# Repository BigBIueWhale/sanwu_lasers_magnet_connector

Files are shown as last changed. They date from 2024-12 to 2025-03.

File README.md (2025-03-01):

# Problem Statement

**Disclaimer:** This project is not affiliated with SanwuLasers™️ company.

SanwuLasers™️ Lasers such as Striker, Challenger II, "Laser Rangers" all have option for high powered blue diode (~7 watts).

SanwuLasers™️ offers flashlight adapters that [can be screwed onto the laser head](./docs/laser_and_flashlight_adapter.jpg). It's generic, the flashlight adapter fits all of the aforementioned host types.

Problem is: It takes way too long to physically unscrew the flashlight adapter, and it's way too annoying to screw it back on. It should be possible to just pull it off, and snap it right back into place 🧲.

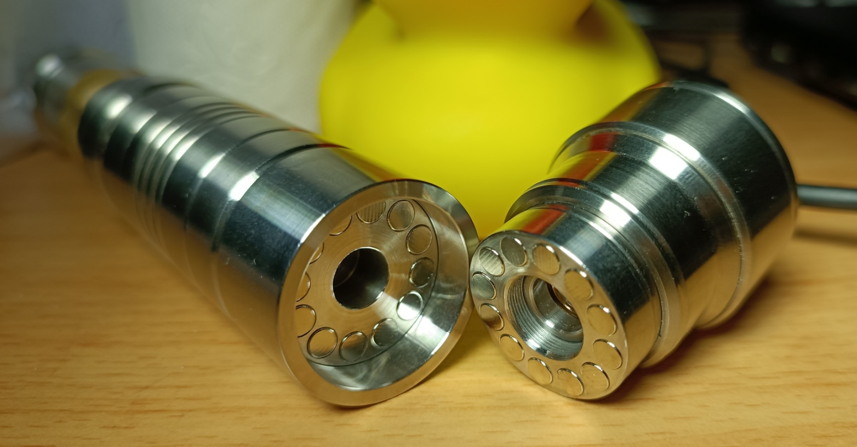
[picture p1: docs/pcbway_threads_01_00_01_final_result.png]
Fully assembled


# Solution

[Manufacture](#manufacture-with-pcbway-cnc) and [assemble](#assembly) a stainless steel adapter, converting the screw-on mechanism into  a robust magnetic mechanism.

## Manufacture with PCBWay CNC

### Compatibility

The current [rangers_guard_sleeve_01_00_01](#rangers_guard_sleeve_01_00_01) piece is only compatible with Sanwu **"Laser Rangers"** with [body models 1, 2, 4, 5, 7, 8](./docs/laser_rangers_body_models.png) due to [the 2-stair design](./docs/guard_sleeve_01_00_01_rangers_head.jpg).\
I recommend body model 7 or model 2, they have good grip ✊.

### Price
Price overview of [January 2025 order](./docs/pcbway_order_price_01_00_00.png) containing 3 items [male_thread_01_00_00](#male_thread_01_00_00) + [female_thread_01_00_00](#female_thread_01_00_00) + [rangers_guard_sleeve_01_00_01](#rangers_guard_sleeve_01_00_01):
1. **Items**: $113.73 USD (= ₪405.52 New Israeli Shekels)
2. **Shipping Fedex to Israel**: $40 USD (= ₪142.62 New Israeli Shekels)
3. **Israel customs import tax 🖕**: ₪235.46 New Israeli Shekels.\
Automatically charged by FEDEX CAYMAN ISLANDS same day as order arrival because I have a Fedex account.

**Total**: ~ ₪783.6 New Israeli Shekels when ordering to Israel.

### Order

PCBWay CNC service has shown ability to successfully manufacture [the threads](#threads) needed for the parts in this project (as of February 2025), but they don't guarantee successful manufacture of non-standard threads.

1. Sign-in to your PCBWay account, and upload each step file to [PCBWay CNC machining](./docs/pcbway_cnc_machining_upload.png). Start by uploading [male_thread.step](./male_thread_01_00_00/male_thread.step).

2. For all parts, choose material [stainless steel 303](./docs/pcbway_choose_stainless_steel_303.png).

3. For the `male_thread` and `female_thread` parts, click "Yes" on [Do your parts need to tap threads?](./docs/pcbway_click_yes_on_threads_and_tapped_holes.png)\
A [pop-up menu](./docs/pcbway_upload_technical_drawing.png) will appear- upload the relevant technical drawing for the current piece: [male_thread technical drawing](./male_thread_01_00_00/technical_drawing/technical_drawing.png) / [female_thread technical drawing](./female_thread_01_00_00/technical_drawing/technical_drawing.png).\
Leave `Inserts` marked "No" because our parts don't have any inserts.

4. For all parts, choose "Surface Finish" -> `Standard (As-Milled) (Ra 125μin)`.

5. For the `male_thread` and `female_thread` parts, choose "Surface Roughness" -> `125uin/3.2um Ra`.\
You can't change the default surface surface finish on `rangers_guard_sleeve` because we don't have a technical drawing for it.

6. For all parts, choose product description [robot components](./docs/pcbway_product_description_robot_parts.png) for import/customs purposes.\
Not sure if that's the best thing to report for Israeli customs but that's the option I've been choosing.

7. **Repeat steps 2 -> 6** for [female_thread.step](./female_thread_01_00_00/female_thread.step) and then again for [rangers_guard_sleeve.step](./rangers_guard_sleeve_01_00_01/rangers_guard_sleeve.step).\
Fill in the items for all 3 orders in the same window, and each time scroll down and [select additional files](./docs/pcbway_select_additional_step_files.png).

8. Click botton [submit request](./docs/pcbway_ready_to_submit_request.png).

9. After ~24 hours PCBWay will supply you with a price quote- hopefully no higher than initially estimated. Then you'll have the option to make the order (after a human has viewed your request).

10. Once you receive the parts, follow [Assembly](#assembly) steps.

# Development Process

Classical GUI-based CAD softwares are problematic for multiple reasons:

1. Sometimes requires user to draw shapes like an artist 🎨🧑‍🎨 instead of using precise definitions.

2. Write-only designs. A simple change in a basic parameter can require starting the design from scratch.

3. Cost money / require online connection- **FreeCAD 1.0.0** is no good yet. Wasn't able to find option to place multiple evenly-spaced holes around a radius.

4. Not text. Can you search "4.11" and change all occurences to a larger / smaller value? Can you ask ChatGPT for help with your design?

I decided it's more robust to define the 3d design with words and precise measurements than it is to use a GUI software.

Therefore I helped `ChatGPT o1` use Python library `import cadquery as cq` to create my 3d designs.

# Magnets

The custom machined male and female parts have 12 holes each, 3.30mm depth and 4.11mm diameter.

These sizes were fine tuned for a stack of two of the [neodymium disc magnets](./docs/neodymium_magnets_amazon_listing.png) I chose.

According to the listing these are **2mm in height** but notice that the [diameter is greater](./docs/amazon_magnet_diameter_not_as_advertized.jpg) and [height is much less](./docs/amazon_magnet_height_not_as_advertized.jpg) than advertized.

When stacking two magnets per hole, the magnets are **very** slightly extruding (0.15mm), for total of 0.3mm extra [gap created by the magnets](./docs/tight_fit_despite_magnets_slightly_extruding.jpg).

The small gap is also a feature- it causes the flashlight adapter to **not** be air-tight which makes it easier to change focus without causing a vacuum (which was always a feature that was bothering me in the default flashlight adapter behaviour).

I originally chose 4.04mm hole width but that was not enough, so then I changed the design to 4.16mm hole to make it easier to push-in the magnets. I then changed the design to 4.11mm diameter for a tight fit- so you now have to push-in each bottom magnet with a bench vice.

# Threads

Sanwu uses the following threading specs for the laser head and attachments:

- Male:
  ```txt
  CNC machined
  Metric right-handed male threaded rod
  11.45mm diameter teeth (crest-to-crest). 0.05mm smaller diameter than the female tap.
  0.5mm pitch
  3mm length out of which only the tip 2mm are threaded and the base 1mm runoff is shaved down and not threaded.
  That's total of 4 threads.
  ```
- Female (laser head):
  ```txt
  CNC machined
  Metric right-handed female
  m11.5x0.5 tap (11.5mm diameter, 0.5mm pitch)
  6mm depth- total of 12 threads
  ```

This adheres to standard: https://www.gewinde-normen.de/en/iso-fine-thread-2.html
```txt
ISO Metric Fine Thread DIN 13-3
Pitch mm: 0.5
Nominal (major) Diameter mm: M 11.5
```
Issue is that the aforementioned size is not a standard combination of **major diameter** + **pitch**.\
PCBWay CNC was able to machine it- because supposedly it's a standard size in China.

# Recreate 3d model from code

You can decide to change parameters in any of [male_thread.py](./male_thread_01_00_00/male_thread.py), [female_thread.py](./female_thread_01_00_00/female_thread.py), [rangers_guard_sleeve.py](./rangers_guard_sleeve_01_00_01/rangers_guard_sleeve.py) then re-run the script to update the design files.

Always update [male_thread_visual.py](./male_thread_01_00_00/male_thread_visual.py) in the same way you updated [male_thread.py](./male_thread_01_00_00/male_thread.py).\
Always update [female_thread_visual.py](./female_thread_01_00_00/female_thread_visual.py) in the same way you updated [female_thread.py](./female_thread_01_00_00/female_thread.py).

If you made a visual change to [male_thread.py](./male_thread_01_00_00/male_thread.py) or [female_thread.py](./female_thread_01_00_00/female_thread.py) then you should update [technical_drawing.png](./male_thread_01_00_00/technical_drawing/technical_drawing.png) / [technical_drawing.png](./female_thread_01_00_00/technical_drawing/technical_drawing.png) in **Microsoft Paint**.

The `XX_visual.py` files exist solely for technical drawing purposes- and each generates a `XX_visual.stl` file.\
Feel free to use [create_images.py](./male_thread_01_00_00/technical_drawing/create_images.py) / [create_images.py](./female_thread_01_00_00/technical_drawing/create_images.py) to generate updated images for use in the the technical drawing you're updating.

## Software Requirements
- Tested on Windows 11 Pro 23H2
- Ran with Python 3.10.6
- Specific versions chose: `pip install cadquery==2.4.0 numpy==1.23.5`

## Assembly

1. Prepare [the male & female pieces](./docs/pcbway_male_female_threads_01_00_00_raw.jpg), [the magnets](./docs/magnets_box_findmag.jpg), and a bench vice.

2. Insert a stack of 2 magnets with your hands into one of the holes- it won't push-in all the way and the top magnet will stick ~1mm out of the hole (as opposed to ~0.15mm when pushed in all the way).

3. Use a bench vice to push the stack all the way down- the bottom magnet is now stuck down there and will never come out, no glue needed.\
The top magnet is slightly sticking out (only ~0.15mm) and in practice is loose.

4. Use a stack of magnets to pull out the top magnet. If it comes out- good!\
If the top magnet doesn't come out by using attraction (due to machining tolerances) even when the entire piece is heated to 50° celsius (expanding the steel), that means we don't have to use glue for that hole.

5. Repeat steps 2 -> 4 for every hole in both pieces male and female. Insert the magnets into the holes in either clockwise or counter clockwise order, placing in the magnets in **alternating polarities**- positive hole, negative hole, positive hole, negative hole. This is so the magnetic power doesn't accumulate. Essentially, so the entire piece as a whole doesn't become significantly magnetic. Also, this make every adjacent pair of magnets attracted to each other so they're "happy to be there".\
We have now finished pushing-in a total of 24 magnets to the bottom of the 24 holes- and they're mechanically held in place quite tightly- and in the correct polarities.

6. Wear black nitrile gloves and protective goggles (laser safety goggles work)- and prepare the [super glue](./docs/good_super_glue_brand.jpg).\
Prepare paper towel as well to wipe off excess super glue. Move entire work area to baking paper surface to avoid sticking.\
Keep a bench vice nearby just in case.

7. **Note:** If a bottom magnet is loose in its hole (due to machining mishaps)- then you can use super glue on the entire stack of 2 magnets in one push. **Never use super glue more than once per hole** because that would cause an unreparable gap between the bottom magnet and the top magnet (due to the dried super glue) then you'll have to throw away the entire piece (I say this from experience). 

8. Apply 1 drop of super glue into one of the holes by tapping the bottom magnet of the hole with the head of the nozzle.

9. Hold the stack of magnets in the correct polarity for the hole, and quickly insert the top magnet and slide off the rest of the stack of magnets (such that now a stack of 2 magnets is in the hole). Quickly wipe the bottom of the magnet stack on paper towel to avoid the negative effect of excess super glue contaminating the magnet stack.\
Immediately push down hard on the just-inserted magnet with the same paper towel while rubbing away excess super glue.\
If even when pushing down with paper towel you see that the magnet isn't pushed-in all the way: use a bench vice ASAP. If only a minute has passed you might still have a chance to push the top magnet down to stop it from permanently sticking out.

10. Don't worry, you can reuse the paper towel because super glue immediately dries when exposed to paper towel. However- after each magnet insertion make sure to wipe off any drips of liquid super glue that may have fallen onto the baking paper's surface.

11. Repeat steps 7 -> 10 for each of the 24 holes.

12. Take a [rangers_guard_sleeve](#rangers_guard_sleeve_01_00_00) and the [male_thread](#male_thread_01_00_00) piece you just inserted 12 pairs of magnets into. Practice sliding the [male_thread](#male_thread_01_00_00) piece [screw side down](./docs/guard_sleeve_01_00_01_rangers_head.jpg) into the top of the [rangers_guard_sleeve](#rangers_guard_sleeve_01_00_00) piece.\
It's actually not that easy to push the piece [all the way down](./docs/guard_sleeve_01_00_01_assembled_bottom_view.jpg) because of the tight tolerance.\
Prepare Q-Tips and paper towel.

13. Precisely apply a small amount of super glue to [the inside of the bottom ring](./docs/guard_sleeve_01_00_01_inside_of_bottom_ring.jpg) then quickly slide-in the [male_thread](#male_thread_01_00_00) all the way down.

14. Very quickly start wiping the [top ring](./docs/guard_sleeve_01_00_01_top_ring.jpg) with paper towel. Just as quickly [wipe the bottom](./docs/guard_sleeve_01_00_01_area_to_wipe.jpg) with Q-tips to avoid any significant width of excess super glue from hardening.

15. If you failed to push all the way down (and the super glue hardened), push the [male_thread](#male_thread_01_00_00) out of the [rangers_guard_sleeve](#rangers_guard_sleeve_01_00_00) using a bench vice. Optionally, take [the female side](./docs/sanwu_striker_adapter_female_view.jpg) of a [Sanwu adapter for striker](./docs/sanwu_adapter_order_separately.png) to [gain leverage](./docs/gain_leverage.jpg) with the bench vice (without damaging our machined part).\
Finally scrape off the previously-applied super glue using a needle or other sharp metal rod, or by pushing in-and-out the [male_thread](#male_thread_01_00_00). Then try again to repeat steps 13 -> 14.

# Release Notes

## female_thread_01_00_00
[female_thread.py](./female_thread_01_00_00/female_thread.py)\
[PCBWay raw result](./docs/pcbway_female_thread_01_00_00_raw.jpg)\
Based on [magnet_holes_01_00_01](#magnet_holes_01_00_01)\
[Final result](./docs/pcbway_threads_01_00_01_final_result.png)

- Only female, not generic. With builtin female threading (screw hole) instead of relying on [purchasing adapter from Sanwu](#threads) and using angle grinder.

- Smaller cylinder diameter- 24mm instead of 28mm. This is possible because that pesky Sanwu adapter used to take up 17.6mm in diameter where we couldn't place any magnets.

- Height- 6mm instead of 8.3mm. Small improvement to bulkiness in addition to the smaller male piece.

- To be utilized with [rangers_guard_sleeve_01_00_00](#rangers_guard_sleeve_01_00_00) instead of [rangers_guard_sleeve_01_00_01](#rangers_guard_sleeve_01_00_01).

- [Technical drawing](./female_thread_01_00_00/technical_drawing/technical_drawing.png) so that PCBWay can correctly manufacture the threads.

- 12 magnet holes instead of 16 (because we're now smaller). Should still be strong enough.

- 4.16mm magnet holes diameter was too big so I changed the design to 4.11mm diameter for a perfect fit.

- 1 unit ordered [via PCBWay](./docs/pcbway_order_price_01_00_00.png)

## male_thread_01_00_00
[male_thread.py](./male_thread_01_00_00/male_thread.py)\
[PCBWay raw result top](./docs/pcbway_male_thread_01_00_00_raw.jpg)\
[PCBWay raw result bottom](./docs/pcbway_male_female_threads_01_00_00_raw.jpg)\
Based on [magnet_holes_01_00_01](#magnet_holes_01_00_01)\
[Final result](./docs/pcbway_threads_01_00_01_final_result.png)

- Only male, not generic. With builtin male threading (screw) instead of relying on [purchasing adapter from Sanwu](#threads) and using angle grinder.

- Smaller cylinder diameter- 24mm instead of 28mm. This is possible because that pesky Sanwu adapter used to take up 17.6mm in diameter where we couldn't place any magnets.

- Height- 4.3mm (not including male thread rod) instead of 8.3mm. This makes the entire assembled system less bulky.

- To be utilized with [rangers_guard_sleeve_01_00_00](#rangers_guard_sleeve_01_00_00) instead of [rangers_guard_sleeve_01_00_01](#rangers_guard_sleeve_01_00_01).

- [Technical drawing](./male_thread_01_00_00/technical_drawing/technical_drawing.png) so that PCBWay can correctly manufacture the threads.

- 12 magnet holes instead of 16 (because we're now smaller). Should still be strong enough.

- 4.16mm magnet holes diameter was too big so I changed the design to 4.11mm diameter for a perfect fit.

- 1 unit ordered [via PCBWay](./docs/pcbway_order_price_01_00_00.png)

## rangers_guard_sleeve_01_00_01
[rangers_guard_sleeve_01_00_00.py](./rangers_guard_sleeve_01_00_01/rangers_guard_sleeve.py)\
[PCBWay raw result](./docs/pcbway_guard_sleeve_01_00_01_raw.jpg)\
[Final result](./docs/pcbway_threads_01_00_01_final_result.png)

- Slightly narrower steps- so the fit onto the Laser Rangers head is more snug and secure (less dependent on screw mechanism)

- Different length and internal and external diameters to fit the now smaller and thinner [male_thread](./male_thread_01_00_00/) and [female_thread](./female_thread_01_00_00/)

- Compatible with [male_thread_01_00_00](#male_thread_01_00_00) & [female_thread_01_00_00](#female_thread_01_00_00).

- 1 unit ordered [via PCBWay](./docs/pcbway_order_price_01_00_00.png)

## rangers_guard_sleeve_01_00_00
[rangers_guard_sleeve_01_00_00.py](./old/rangers_guard_sleeve_01_00_00.py)\
[PCBWay raw result](./docs/pcbway_guard_sleeve_01_00_01_raw.jpg)

- Designed to be attached on with [super glue](./docs/bad_super_glue_brand.jpg) to a `magnet_holes` piece (to the male side that's screwed onto the laser head).

- Keeps flashlight head secure on Laser Rangers model so it can only be pulled off straight-up which is the direction the magnets are strongest in.

- Fills-in ugly gap at the stairs of the **Laser Rangers** laser head- only compatible with [models 1, 2, 4, 5, 7, 8](./docs/laser_rangers_body_models.png). I recommend model 7 or model 2.

- Compatible with [magnet_holes_01_00_00](#magnet_holes_01_00_00) and with [magnet_holes_01_00_01](#magnet_holes_01_00_01)

- 2 units ordered [via PCBWay](./docs/pcbway_order_01.png)

## magnet_holes_01_00_01
[magnet_holes_01_00_01.py](./old/magnet_holes_01_00_01.py)\
[PCBWay raw result](./docs/pcbway_magnet_holes_and_guard_sleeve.jpg)

- 4.16mm diameter magnet holes for better fitting, instead of 4.04mm

- 2 units ordered [via PCBWay](./docs/pcbway_order_01.png)

## magnet_holes_01_00_00
[magnet_holes_01_00_00.py](./old/magnet_holes_01_00_00.py)\
[Xometry raw result](./docs/xometry_raw_result.jpg)\
[Final result](./docs/xometry_final_result.jpg)

- 4.04mm diameter magnet holes

- Generic- can be used with `rangers_guard_sleeve_01_00_00`.

- Generic- each piece can be used with [Sanwu Adapter](#threads) male or female.

- Generic- since the magnets [perfectly fit](./docs/tight_fit_despite_magnets_slightly_extruding.jpg), the male and female sides are interchangeable.

- 5 units ordered with https://get.xometry.eu/payments/ec0325ff-71c7-4672-9496-26f8077902b1

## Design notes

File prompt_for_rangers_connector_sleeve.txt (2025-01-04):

I had this CNC machined in stainless steel 303. Specifically I had two of these manufactured to be used one on top of the other (face to face, magnets attaching to each other).

Now I need you to create an entirely new Python file that produces for me: `rangers_guard_sleeve_01_00_00.py`.

I will provide the entire readme of my full project for you to glance at to give you further context, **then** I will explain the requirements for the `rangers_guard_sleeve` after you read the readme, and see the provided example code.

magnet_holes_01_00_01.py
```py
"""
Creates a 'toilet paper roll' shaped cylinder with:
  - Outer diameter: 28.0 mm
  - Inner hole diameter: 17.6 mm (fully through)
  - Height: 8.3 mm
Then adds 16 equally spaced magnet holes at the top:
  - Diameter: 4.10 mm
  - Depth: 3.3 mm
  - Circle radius for hole centers: 11.4 mm
Exports the model to both STL and STEP formats.
"""

import cadquery as cq

# === 1. Create main cylinder ===
#   - Outer diameter: 28 mm → radius = 14 mm
#   - Height: 8.3 mm
model = (
    cq.Workplane("XY")
    .circle(14)        # radius for 28 mm diameter
    .extrude(8.3)      # height
)

# === 2. Hollow out the center (like a toilet paper roll) ===
#   - Through-hole with diameter: 17.6 mm → radius = 8.8 mm
model = (
    model
    .faces(">Z")               # pick the top face
    .workplane()               # create a new workplane on that face
    .hole(17.6)                # cut a 17.6 mm diameter hole all the way through
)

# === 3. Drill the magnet holes around the top face ===
#   - 16 holes
#   - Each hole diameter: 4.10 mm
#   - Hole depth: 3.3 mm
#   - Hole centers on a circle of radius: 11.4 mm
#     so they are equally spaced 360/16=22.5 degrees apart
model = (
    model
    .faces(">Z")               # pick the top face again
    .workplane()               # new workplane for drilling
    .polarArray(radius=11.4, startAngle=0, angle=360, count=16, fill=True)  # 16 holes in a full circle
    .hole(diameter=4.10, depth=3.3)  # create the holes as pockets in the top
)

# === 4. Export the final model to both STL and STEP files ===
output_file_step = "magnet_holes.step"
output_file_stl = "magnet_holes.stl"

# Export to STEP format
cq.exporters.export(model, output_file_step)

# Export to STL format
cq.exporters.export(model, output_file_stl)

# Print file names for confirmation
print(f"Model exported to: {output_file_step}")
print(f"Model exported to: {output_file_stl}")
```

```md
# Problem Statement

SanwuLasers™️ Lasers such as Striker, Challenger II, Laser Rangers all have option for high powered blue diode (~7 watts).

SanwuLasers™️ offers flashlight adapters that [can be screwed onto the top](./docs/laser_and_flashlight_adapter.jpg). It's generic, the flashlight adapter fits all of the aforementioned host types.

Problem is: It takes way too long to physically unscrew the flashlight adapter, and it's way too annoying to screw it back on. It should be possible to just pull it off, and snap it right back in place 🧲.

[magnet holes standard triangle language](./magnet_holes.stl)

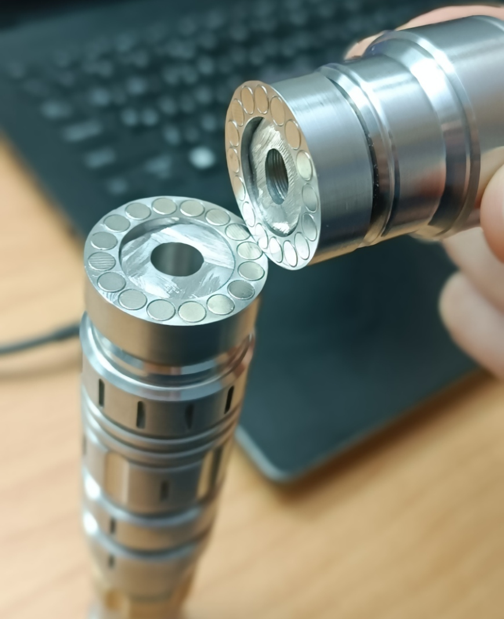
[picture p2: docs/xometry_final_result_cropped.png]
Fully assembled


# Solution

Custom order for CNC machined stainless steel part that converts the screw-on mechanism into a magnetic mechanism!

The flashlight adapter can be ordered with an [Adapter for striker](#threads). This adapter is super useful because it's already threaded with male and female sides.

The generic custom machined part has 16 small holes, each 4.10mm in diameter and 3.30mm depth.

It just so happens that in practice, my choice of 3.30mm depth works with the [neodymium disc magnets](./docs/neodymium_magnets_amazon_listing.png) I chose, which according to the listing are **2mm in height** (apparently they're less). 

It just so happens that the specific magnets I bought, somehow [fit perfectly](./docs/two_stacked_magnets_fit_in_3.3mm_hole_perfectly.jpg) into the 3.3mm hole when two are stacked on each other in each hole and with super glue prepared at the bottom (no super glue between the two magnets).

The magnets are **very** slightly extruding which does cause purple light to be slightly visible when flashlight mode is on, but it's still a [tight fit](./docs/tight_fit_despite_magnets_slightly_extruding.jpg).

The small gap is also a feature- it causes the flashlight adapter to **not** be air-tight which makes it easier to change focus without causing a vacuum (which was a feature that was bothering me in the default flashlight adapter behaviour).

I originally chose 4.04mm hole width but that was not enough to leave room for machine tolerance and temperature changes, so then I changed the design to 4.10mm hole to make it easier to push-in the magnets.

# Process

I learned the recently released `FreeCAD 1.0.0`, but I gave up on the design once I understood that the software requires the user to draw shapes with my laptop's touchpad. I'm not an artist 🎨🧑‍🎨.

I decided it's much more robust to define the 3d design with words and precise measurements than it is to start drawing like a preschool child.

Therefore **for the initial version** I had `ChatGPT o1` write Python code to generate both a `.step` file and an `.stl` file, using [this prompt](./prompt.txt).

I use the `.stl` file to view the design in `Microsoft Paint 3d`, I then uploaded the `.step` file as-is to `Xometry` website.

I chose standard stainless steel [settings in the website](./docs/xometry_order_settings.png) with the lowest tolerance quality.

The reason I chose such a low tolerance quality is that I'm using super glue and I made the holes slightly bigger than they need to be, so it's fine. Also, I want the CNC machine to just do everything automatically to avoice human error.

# Threads

This adapter from SanwuLasers™️ is the base of my design.\
It already comes with [male threads](./docs/sanwu_striker_adapter_male_view.jpg) and [female threads](./docs/sanwu_striker_adapter_female_view.jpg).

The part can be ordered via its [dedicated listing](./docs/sanwu_adapter_order_separately.png) on the website, or as part of the [flashlight converter listing](./docs/sanwu_adapter_in_flashlight_converter_listing.png).

The adapter is 17.55 mm in diameter, so I cut a 17.60mm hole in the cylinder of my custom design.

I [cut the adapter in half](./docs/sanwu_adapter_cut_in_half.jpg) using a [diamond blade circular saw](./docs/angle_grinder/angle_grinder_readme.pdf), sand it down, and super glue the male part into the large hole in one of my generic custom machined parts, and the female part of the adapter from Sanwu into another unit of my generic custom machined part.

This is my alternative to reverse-engineering the threads that Sanwu uses.

Just for general knowledge, Sanwu uses the following threading specs:

- Male:
  ```txt
  CNC machined
  Metric right-handed male threaded rod
  11.45mm diameter teeth (crest-to-crest). 0.05mm smaller diameter than the female tap.
  0.5mm pitch
  3mm length out of which only the tip 2mm are threaded and the base 1mm runoff is shaved down and not threaded.
  That's total of 4 threads.
  ```
- Female (laser head):
  ```txt
  CNC machined
  Metric right-handed female
  m11.5x0.5 tap (11.5mm diameter, 0.5mm pitch)
  6mm depth- total of 12 threads
  ```

I chose to use threads from an existing SanwuLasers™️ adapter instead of printing my custom part [with designed threads](./docs/attempt_design_screw.png) for multiple reasons:
1. 11.5mm diameter is not standard.
2. Thread specification required English language specification, and can only exist in a step file for show (being pretty). This makes the whole process more expensive, and less automatic- it might make it hard for the CNC machine to know what to do!
3. I can always later design another custom stainless steel piece to fit into the generic 17.60mm hole with super glue, and I can decide to make it have threads! This incurs less risk by making the components modular.
4. Generic- single design works as either male or female screw side. Only having to print one step file multiple times is significantly cheaper because it only requires one preparation stage for Xometry.

# Recreate 3d model from code

You can decide to change parameters in [main.py](./main.py) then re-run the script to update the design files.

## Requirements
- Tested on Windows 11 Pro 23H2
- Ran with Python 3.10.6
- Specific versions chose: `pip install cadquery==2.4.0 numpy==1.23.5`

## Run
1. Delete the existing `.step` file and `.stl` file.
2. Run command `python magnet_holes_01_00_01.py` in a cmd Window in the same directory as the project folder.
3. Use the newly created `magnet_holes.stl` and `magnet_holes.step` for the male and female sides (upload to PCBWay CNC machining, or to Xometry).

# Release Notes

## magnet_holes_01_00_01
- 4.10mm diameter magnet holes for better fitting

## magnet_holes_01_00_00
[magnet_holes_01_00_00.py](./magnet_holes_01_00_00.py)\
[Final result](./docs/xometry_final_result.jpg)

- 4.04mm diameter magnet holes
- 5 units ordered with https://get.xometry.eu/payments/ec0325ff-71c7-4672-9496-26f8077902b1
```

# Instructions

Well, you saw what ChatGPT already managed to do, so I already have my hopes up for you to deliver and idiomatic and correct design!

Now let's get back to `rangers_guard_sleeve`.

The goal is to make it so the only way to pull off the flashlight head is directly up, so it cannot possibly accidentally fall off.

The Sanwu Striker has a build that is already sunk in, and that works great in stopping the flashlight adapter from accidentally breaking off / sliding off, so this design is specifically for the Sanwu Laser Rangers model which doesn't have that builtin fortunate compatibility.

Since we're designing the sleeve specifically for the `Rangers` we'll also make some cuts for the "stairs" that are manufactured into the head of most Laser Rangers models from Sanwu Lasers™️. These cuts won't be compatible with body types 3, 6, 9 (as seen in the listing at https://www.sanwulasers.com/product/laserrangers) which only have one stair on the head.

1. Start with a 30.20mm diameter, 23.2mm height cylinder as the base shape.

This is purposefully ~2mm wider than the 28mm diameter `magnet_holes`, to give us a 1mm wall thickness after some pockets, at the thinnest part of the design (which is the minimum for stainless steel).

2. Cut out a circular pocket 21.10mm in diameter from the center of the bottom of the base cylinder all the way to the top.

This is to fit the thinnest shape in this design- the top stair that is 21.00mm in diameter

3. Cut out a centered circular pocket at the top of the base cylinder, should be 28.10mm diameter pocket that has a 16.90mm depth.

Purpose: to tightly fit the bottom `magnet_holes` (male) piece as a structural hold to this entire design, with superglew to the base male piece that is screwed on to the laser head.\
16.9mm is the height of 2 `magnet_holes` + the gap between them.\
28.20mm is slightly wider than the 28mm wide `magnet_holes` cylinder diameter.

4. Cut out a slightly wider centered circular pocket at the top of the base cylinder (in addition to the one we already drilled out at the top), should be 28.20mm diameter pocket and 8.40mm depth.

Purpose: loosely fit the top `magnet_holes` (female) piece and stop it from accidentally disattaching while not blocking a user from yanking it upwards.\
8.40mm is slightly taller than 8.30mm which is the height of a single `magnet_holes` piece.\
28.20mm is purposefully wider than the 28mm wide `magnet_holes` cylinder diameter, and leaves walls that are exactly 1mm thick.

4. Cut out a wider centered circular pocket at the bottom of the base cylinder (in addition to the one we already drilled out at the bottom). It should be 25.10mm in diameter and 4.00mm in depth.

This is for the bottom stair which is 25.00mm in diameter.\
The total hight of the area of the stairs we want to encompass is 6.30mm in height, and I measured that for at least 2.30mm out of that total stair height the **small** stair is no more than 21.10mm. The pocket for the small stair was already dug out in an earlier step, therefore in this step we only dig in 6.30mm - 2.30mm == 4.00mm from the bottom.

Get to work!

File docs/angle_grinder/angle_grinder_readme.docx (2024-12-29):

README by Ronen Zyroff

Date of arrival from Amazon: 29 December 2024

Use with the provided Metal Master diamond cutting disc 3-inch. Cuts stainless steel like butter!

Do not use the blades that came with the angle grinder that are made of epoxy resin with sandpaper. They absolutely can explode in your face. You can use the fully-metal wood cutter that came with the angle grinder. But never use blades that look like you can snap with your fingers.

The internal diameter of the diamond blades was too small for this model of angle grinder (9.5mm instead of 10mm) so I rubbed sandpaper on the internal circle until enough steel was eroded away to make the blade perfectly fit into the angle grinder center holder (~20 iterations of sandpaper rubbing for each blade).

Do not screw / unscrew / maintain anything while batteries are in.

Insert the blade such that the red side without text is facing outward, and the text is hidden by the body of the angle grinder. Then put the washer (smooth side facing away from the angle grinder), then screw the screw and tighten it using the provided hex wrench.

The hand that’s cutting should always have anti-cut gloves- that are not too bulky- you don’t want the blade to get caught on some fabric.

Only operate while wearing a coat that protects neck, and motorcycle helmet- by extension only operate in a very cold place because the safety measures will make you hot.

Only operate while stabilizing with both hands. One hand is the one holding the hold-switch to keep on, the other hand should hold the engine body tightly (without blocking the air intakes). It’s super important to hold tight, because an angle grinder can easily and suddenly get caught on a piece of metal wire or large mass and jerk out of your hands!

Do a dry run- get to full speed in air without actually cutting anything. Take out the battery and make sure that the screw is still as tight as you made it originally (make sure it didn’t get lose). Also, notice any wobbling. There shouldn’t be any wobbling. Practice avoiding automatic mode- you want to have to continue pushing constantly. Automatic mode is unsafe.

This angle grinder is purposefully very weak and small. You can fully stop the blade during operation by pushing onto a piece of hard metal. You can (and should) slow down the blade during operation by only briefly pushing the on button intermittently. Oh, and during cutting don’t go too deep too fast. Just push onto the metal piece being cut before the blade starts spinning so that the blade has a hard time gaining speed. Prefer low speeds! (no actual setting control speed).

Prefer surface cuts to deep cuts. During deep cuts the blade might suddenly get blocked by mass of metal and try to jerk the angle grinder out of your hands. You could lose a finger. Prefer slow and even cuts rather than deep and fast cuts.

Only cut small pieces of metal that are tightly held with a vice. Optionally use cookie silicon with the vice, to keep a good grip.

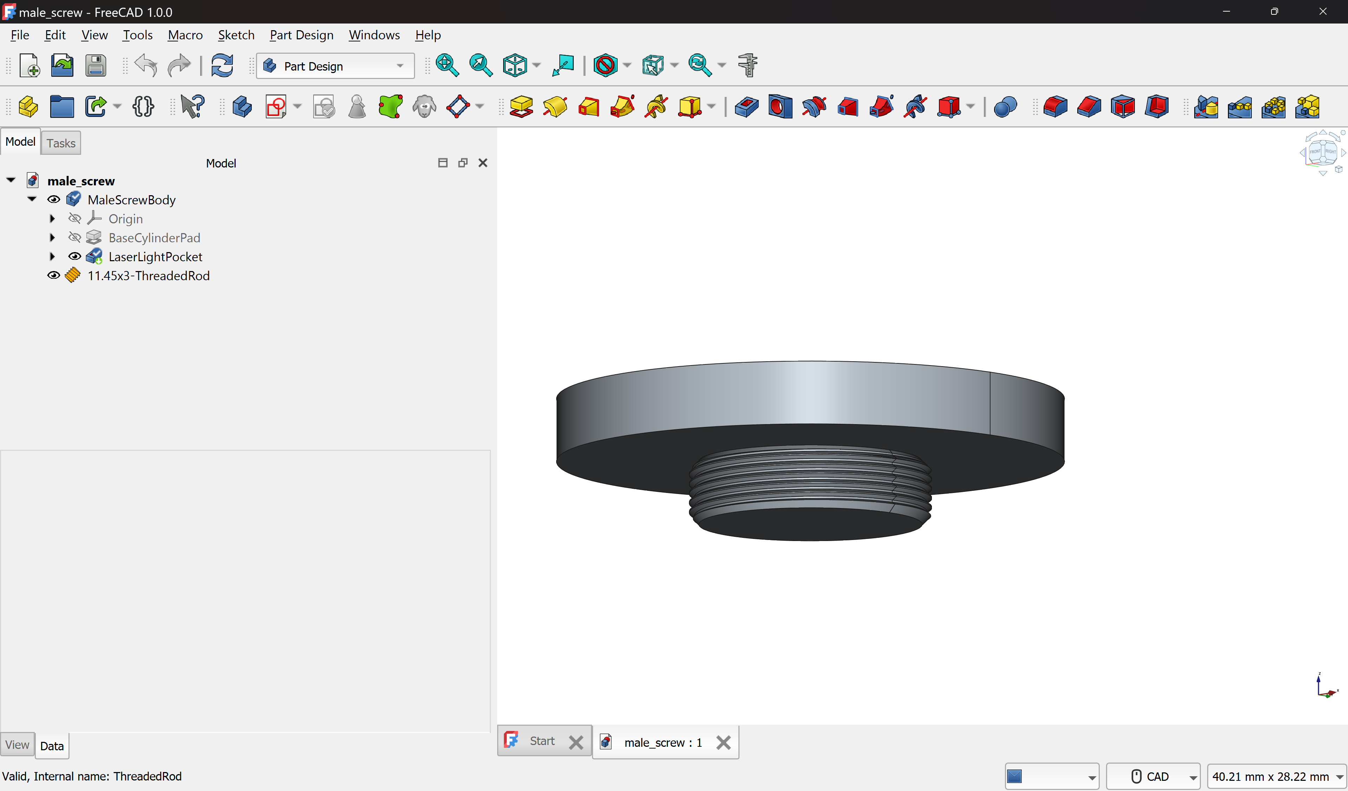
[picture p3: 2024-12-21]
docs/attempt_design_screw.png

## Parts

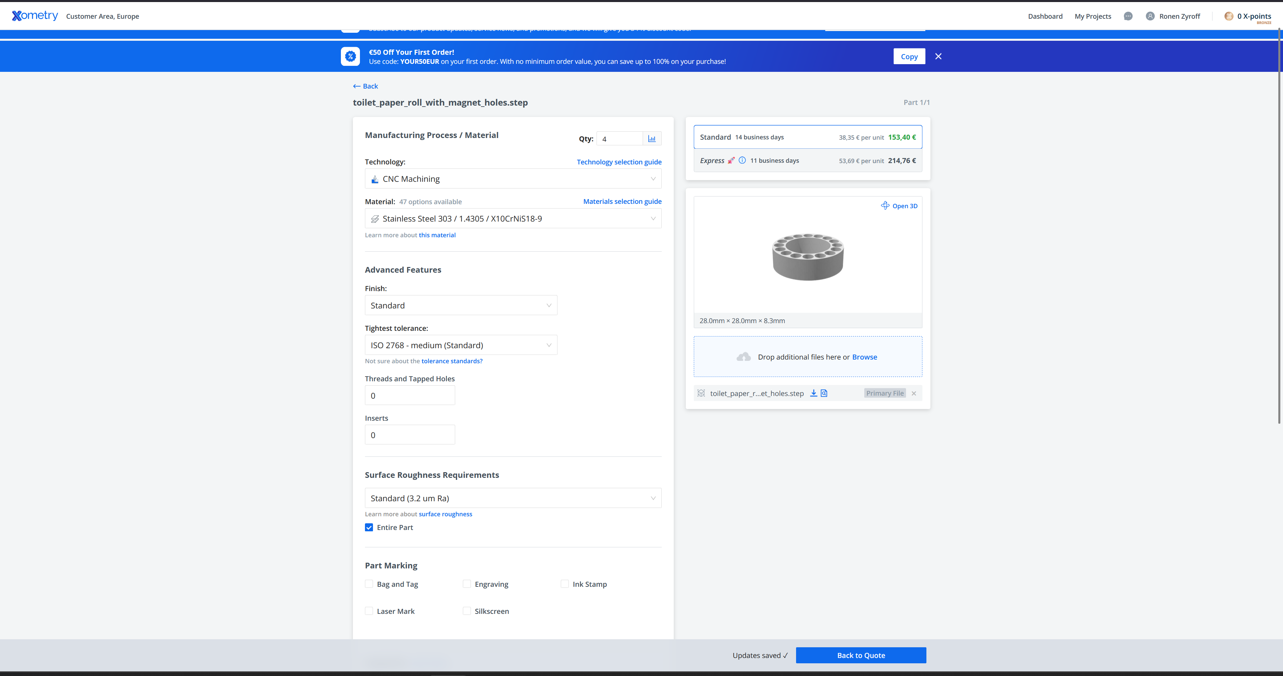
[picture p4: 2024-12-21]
docs/xometry_order_settings.png

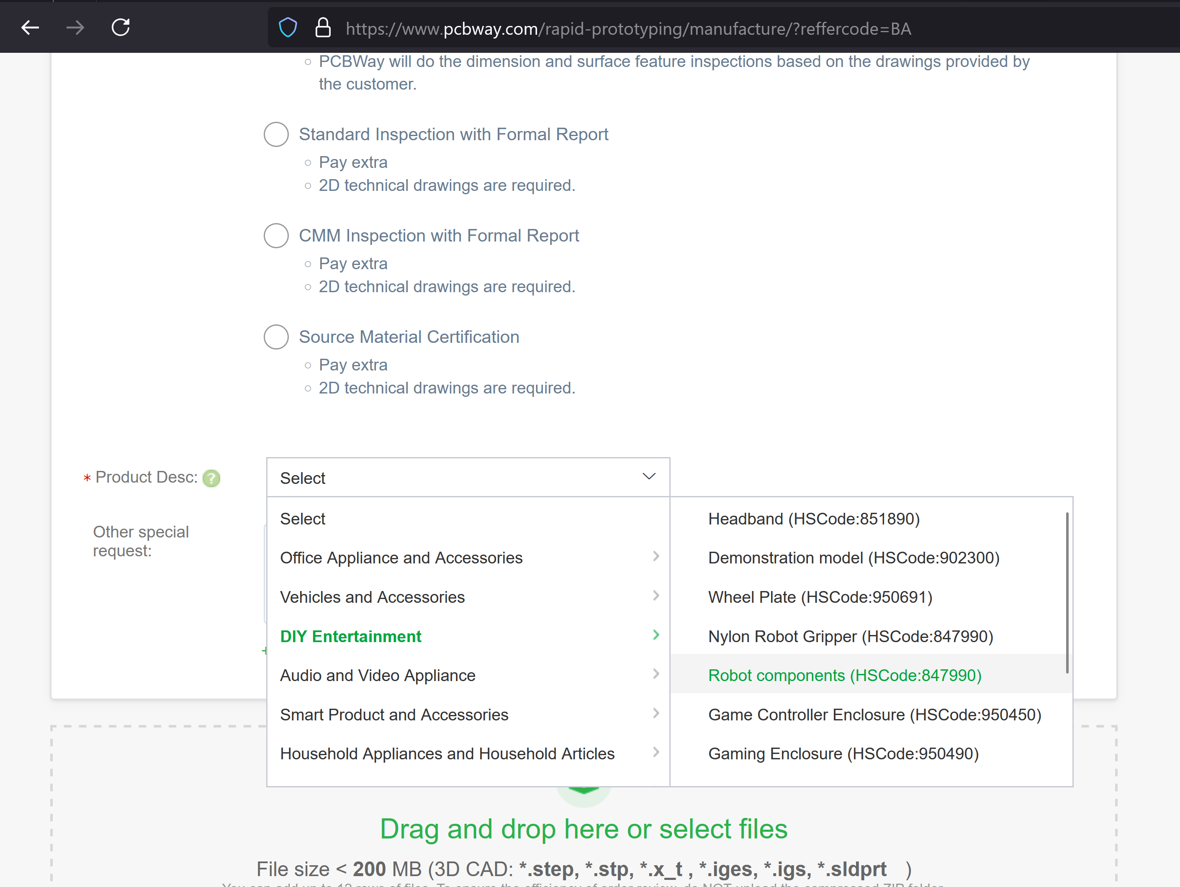
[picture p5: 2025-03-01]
docs/pcbway_product_description_robot_parts.png

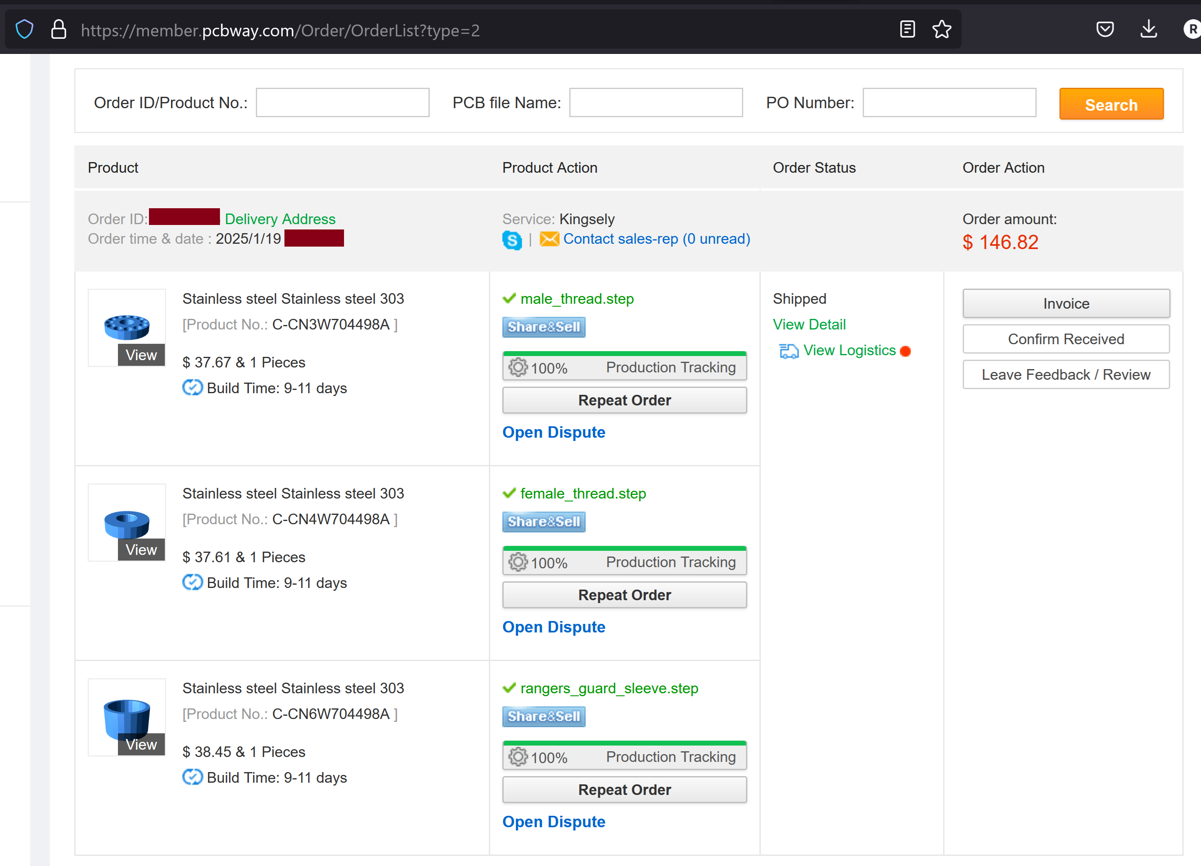
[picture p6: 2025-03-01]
docs/pcbway_order_price_01_00_00.png

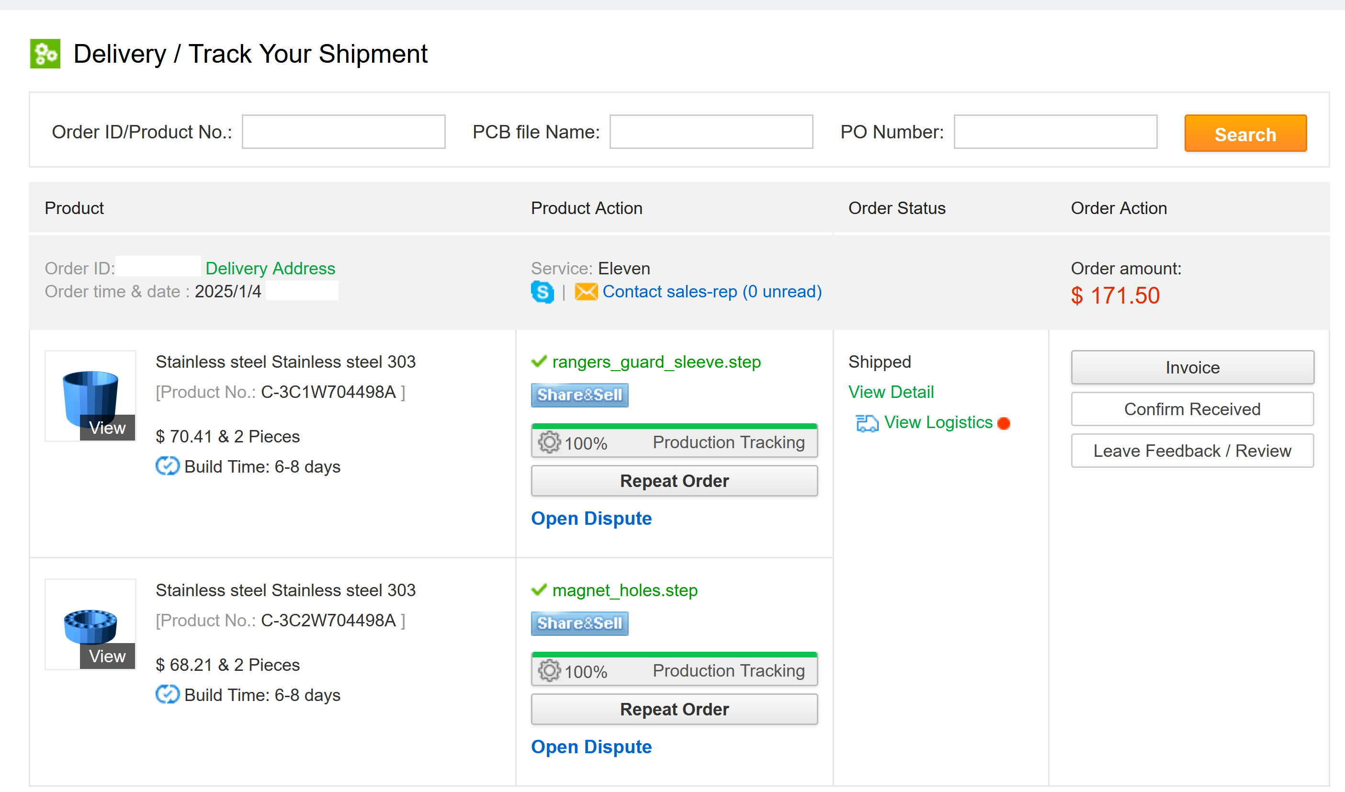
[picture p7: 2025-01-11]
docs/pcbway_order_01.png

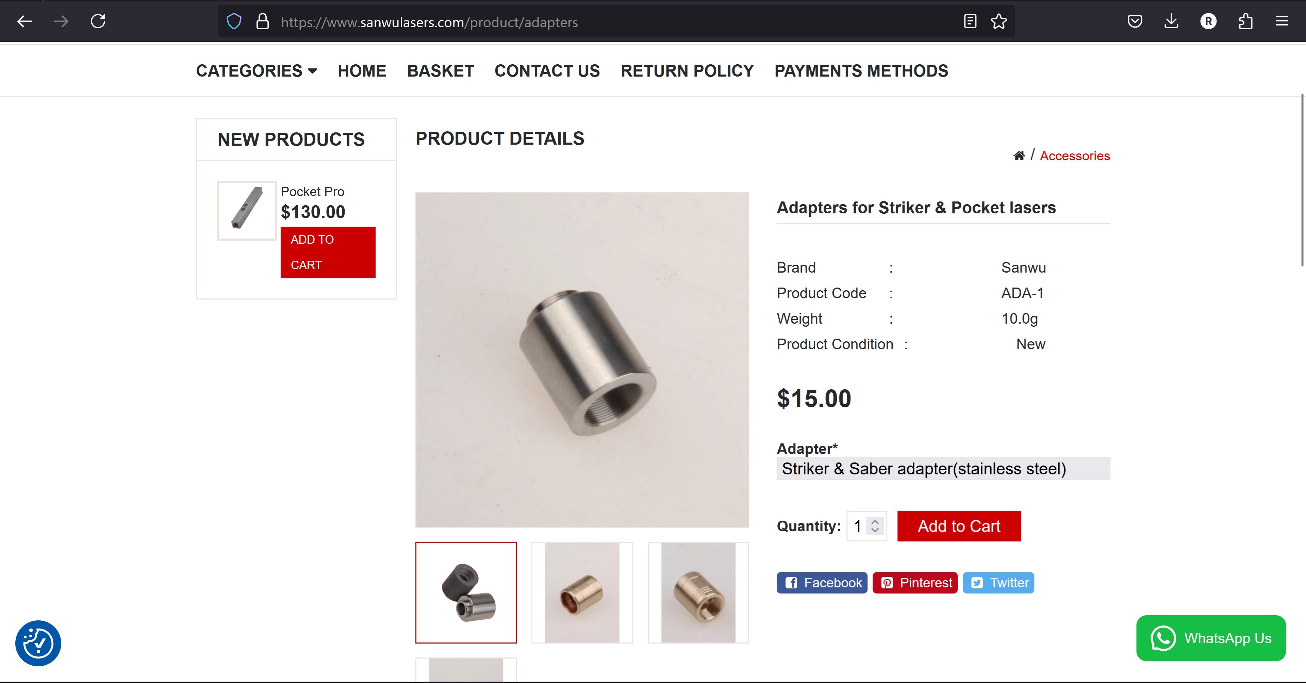
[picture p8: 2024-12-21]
docs/sanwu_adapter_order_separately.png

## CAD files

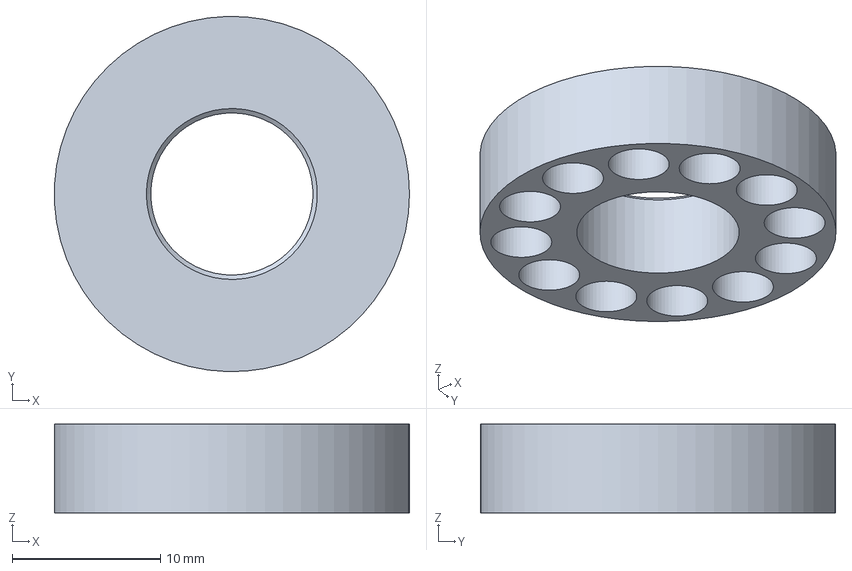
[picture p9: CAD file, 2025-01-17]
female_thread_01_00_00/female_thread.step
24.0 x 24.0 x 6.00 mm

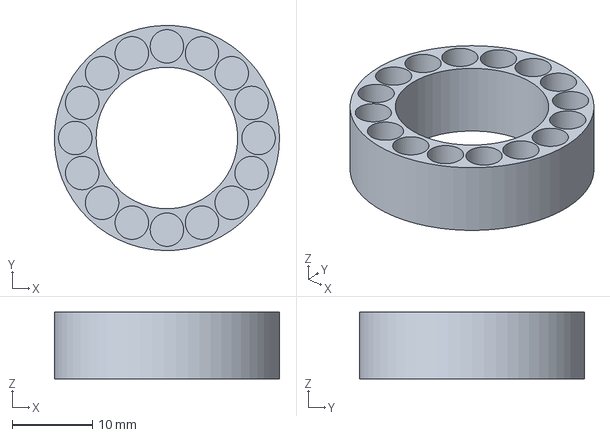
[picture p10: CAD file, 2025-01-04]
magnet_holes.step
28.0 x 28.0 x 8.30 mm

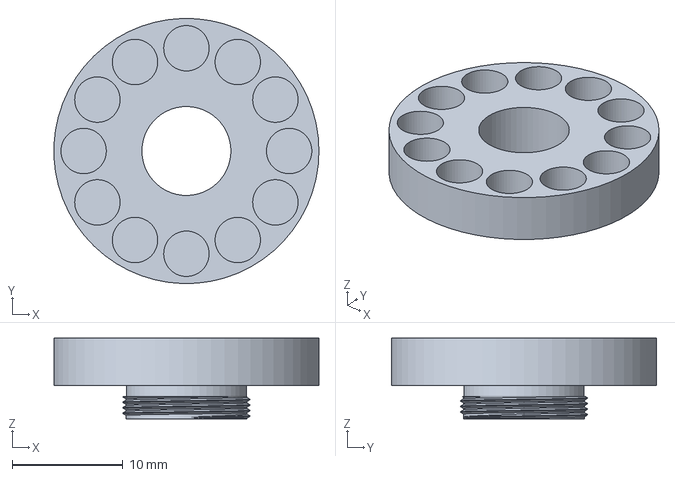
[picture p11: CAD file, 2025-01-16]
male_thread_01_00_00/male_thread_visual.step
24.0 x 24.0 x 7.30 mm

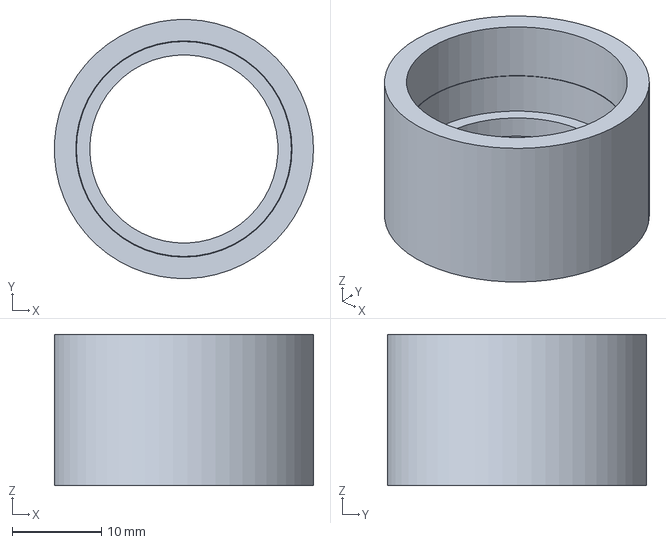
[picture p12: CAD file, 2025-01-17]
rangers_guard_sleeve_01_00_01/rangers_guard_sleeve.step
29.0 x 29.0 x 16.9 mm

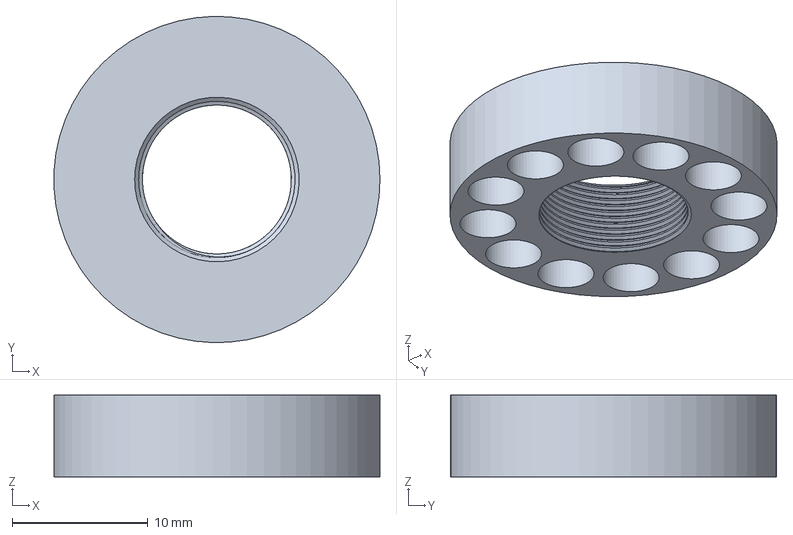
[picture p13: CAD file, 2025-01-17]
female_thread_01_00_00/female_thread_visual.step
24.0 x 24.0 x 6.00 mm

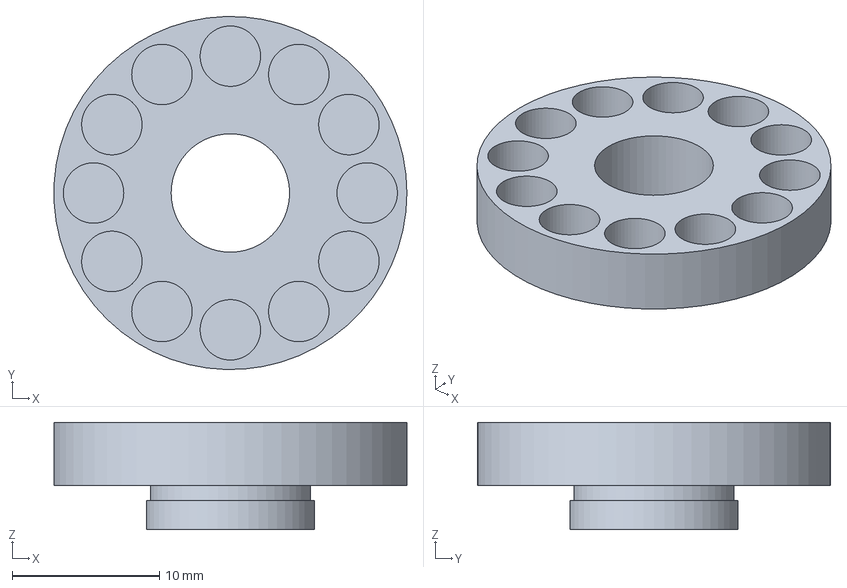
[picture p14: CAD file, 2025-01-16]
male_thread_01_00_00/male_thread.step
24.0 x 24.0 x 7.30 mm

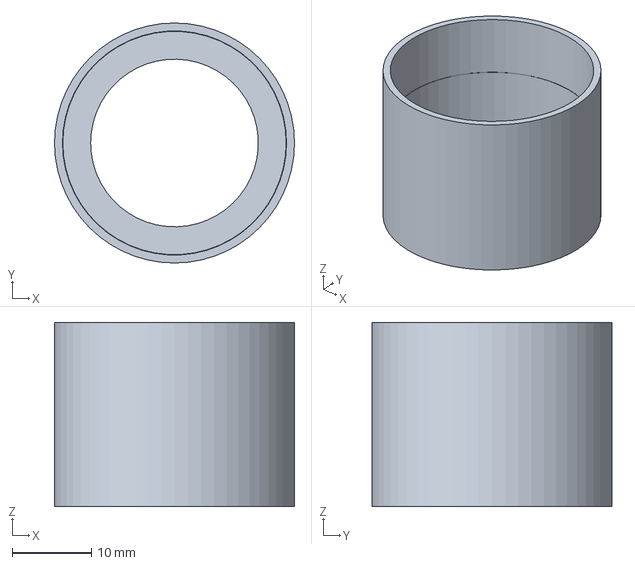
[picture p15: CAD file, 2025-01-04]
rangers_guard_sleeve.step
30.2 x 30.2 x 23.2 mm

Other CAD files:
toilet_paper_roll_with_magnet_holes.step
female_thread_01_00_00/female_thread.stl
female_thread_01_00_00/female_thread_visual.stl
magnet_holes.stl
male_thread_01_00_00/male_thread.stl
male_thread_01_00_00/male_thread_visual.stl
old/magnet_holes.stl
old/rangers_guard_sleeve.stl
rangers_guard_sleeve.stl
rangers_guard_sleeve_01_00_01/rangers_guard_sleeve.stl

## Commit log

2024-12-21 Initial commit, but pretty much done
    [toilet_paper_roll_with_magnet_holes.step, toilet_paper_roll_with_magnet_holes.stl]
2024-12-21 Show attempt at creating screws with cad
2024-12-27 More info about threads, still not sure about them
2024-12-27 Clarify which male and female connectors I'm refering to
2025-01-03 New version with wider holes for magnets
    [magnet_holes.step, magnet_holes.stl, toilet_paper_roll_with_magnet_holes.stl]
2025-01-04 Update readme, realize that the magnets are wider than expected
    [magnet_holes.step, magnet_holes.stl, rangers_guard_sleeve.step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]
2025-01-11 Attempt to save costs
    [male_head.step, male_head.stl]
2025-01-11 Working on specifying threads in the cad model
2025-01-11 WIP working on threading specification
2025-01-11 Failed to create cad model with threads
2025-01-15 Working on threads explicit male female piece to replace generic part which requires angle grinder
    [male_head.step, male_head.stl, male_thread.step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]
2025-01-15 Slowly creating infrastructure for technical drawing
    [male_thread.step, male_thread.stl]
2025-01-15 Add visual representation of threads
    [male_thread_visual.step, male_thread_visual.stl]
2025-01-15 8.05 laser passthrough hole instead of 8.00. Improved technical images
    [male_thread.step, male_thread.stl, male_thread_visual.step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]
2025-01-15 More accurate minor diameter
    [male_thread.step, male_thread.stl, male_thread_visual.step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]
2025-01-15 Full technical drawing for male_thread
    [male_thread.step, male_thread_visual.step, male_thread_visual.stl]
2025-01-15 Created female_thread side. WIP
    [female_thread.step, female_thread.stl]
2025-01-15 Hmm 11.55mm doesn't make any sense for female starting hole
2025-01-16 Fix some mistakes in male_thread- leave more floor room for magnet holes, smaller diameter for magnet holes, update technical drawings and readme
    [male_thread.step, male_thread.stl, male_thread_visual.step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]
2025-01-16 Clean up top directory. Hopefully from now on we will start using designed threads instead of manually operating an angle grinder
    [magnet_holes.step, magnet_holes.stl, rangers_guard_sleeve.step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]
2025-01-16 New guard sleeve is much bulkier, probably gonna print from Titanium
    [female_thread.step, female_thread.stl, male_thread.step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]
2025-01-16 Yup, looks good to me
    [rangers_guard_sleeve.step, rangers_guard_sleeve.stl]
2025-01-16 WIP female thread
2025-01-16 Yeah, still probably gonna print this out of titanium
    [rangers_guard_sleeve.step, rangers_guard_sleeve.stl]
2025-01-17 No decorative groove. Too complicated
    [rangers_guard_sleeve.step, rangers_guard_sleeve.stl]
2025-01-17 Good old fashioned guard_sleeve but shorter and 1mm less wide
    [rangers_guard_sleeve.step, rangers_guard_sleeve.stl]
2025-01-17 Fix female thread hole size
    [female_thread.step, female_thread.stl]
2025-01-17 Document new design with machined threads
2025-01-17 Classic documentation- photograph of received PCBWay parts
2025-01-17 Implemented female_thread_visual.py. Version of female_thread.py that shows the threads visually
    [female_thread.step, female_thread_visual.step, female_thread_visual.stl]
2025-02-28 Hmm PCBWay was able to machine the M11.5x0.5 threads- both male and female according to specification
2025-03-01 Rewrite readme for machined threads (based on technical drawing)
